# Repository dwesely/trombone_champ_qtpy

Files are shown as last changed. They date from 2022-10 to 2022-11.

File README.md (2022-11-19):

Moved into https://github.com/dwesely/trombone_champ, this branch is archived.

# Controller for trombone champ game

Control Trombone Champ by emulating a mouse with a QT-PY 2040 and VL53L0X distance sensor. This project was inspired by the [Adafruit Trombone Champ controller](https://learn.adafruit.com/circuitpython-trombone-champ-controller) by Liz Clark.

 This is a pared-down version of one I made [based on the Trinket m0](https://github.com/dwesely/trombone_champ_trinket).

## Operation

### Select precision
The 3-way switch specifies the precision when the device is plugged in. If the switch is in the middle position, the timing budget is set to 30ms. If the switch is set to one of the other positions, the timing budget will be set according to the table below. Blinks indicate which position was read.

The setting is only read once. To adjust the setting, unplug the device and plug it back in.

| Switch position | Timing Budget | Visual Indicator |
| --- | --- | --- |
| Left  | 20ms  | 2 blinks |
| Middle  | 30ms  | 3 blinks |
| Right  | 40ms  | 4 blinks |

### Select mode

3-way switch allows orientation to be inverted, or to disable the mouse emulation (so it doesn't interfere with operation outside the game).

When the switch is in the middle, no movement reports will be sent, and the scroll wheel (rotary encoder) will be operational.

When the switch is on one side, the distance measured by the device will be translated to the mouse position on the screen (farther distance = higher mouse).
When the switch is on the opposite side, the distance will be inverted (farther distance = lower mouse).

### Toot

The momentary switch clicks the left mouse button, activating toot.

### Navigation

Between songs, set to the 3-way switch to the middle to deactivate the vertical mouse, and to activate the scroll wheel. A rotary encoder acts as mouse wheel and the right mouse button. Scrolling the rotary encoder will scroll through available songs.

Hit the "Enter" key on the keyboard to select a song.

### Scaling Factor

You can adjust the potentiometer to set a scaling factor, to make the maximum detected distance higher or lower. This is used to make operation more comfortable for people with different sizes of arms.

## Other features 

Hardware debounce using a schmitt trigger to clean up "toot" command signal without adding processing complexity.

On board RGB LED indicates which which timing budget is selected, so the measurement precision can be changed without recoding.

JST connectors for input devices. 

### Libraries used
* adafruit_vl53l0x
* adafruit_bus_device
* neopixel
* [mouse_abs](https://gist.github.com/bitboy85/cdcd0e7e04082db414b5f1d23ab09005)

### Parts list
* QT PY RP2040 (Digikey: 1528-4900-ND)
* Adafruit VL53L0X Time of Flight Distance Sensor (Digikey: 1528-1814-ND)
* SN74AHC14N Schmitt Trigger (Digikey: 296-4550-5-ND)
* ANT13SECQE 3-way switch SPDT, ON-OFF-ON (Digikey: 2449-ANT13SECQE-ND)
* Momentary switch
* Rotary encoder
* 10k ohm linear rotary potentiometer
* (x8) 10k ohm 1/4 W resistor 
* (x4) 100nF ceramic capacitor
* JST connector sets (x1 2-pin, x1 4-pin, x1 5-pin)
* Generic toy foam dart gun as a project case (dollartree.com: SKU 323010)

### Connections
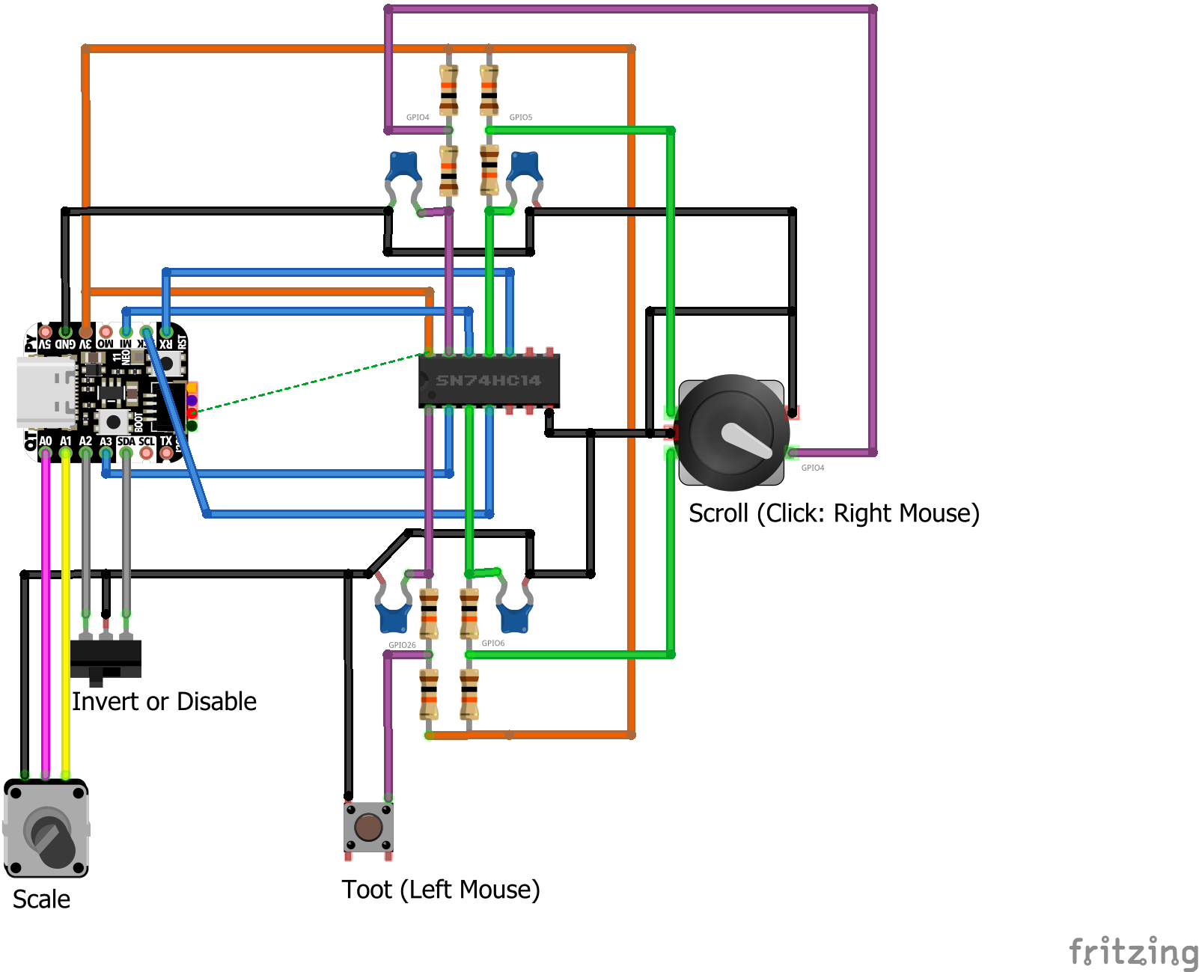
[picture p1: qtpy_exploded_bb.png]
Fritzing representation of parts and connections


## Lessons learned
* Rotary encoder pins must be sequential on the QT PY: https://github.com/adafruit/circuitpython/issues/5334
* The toy gun worked very well as a case, there was fairly little modification
* The mouse_abs library tended to scroll endlessly until I added "self.report[5] = 0" to the report functions.

The following image is a Fritzing representation of the collapsed circuit. Using 7-pin female headers, the QT PY was raised above the Schmitt Trigger, which was mounted using a 14-pin DIP socket. The ceramic capacitors are not shown in this representation, but they fit beneath the Schmitt Trigger, inside the DIP socket. This is probably a terrible way to do it, but it worked enough for me, and it looked cool in the foam dart gun case.

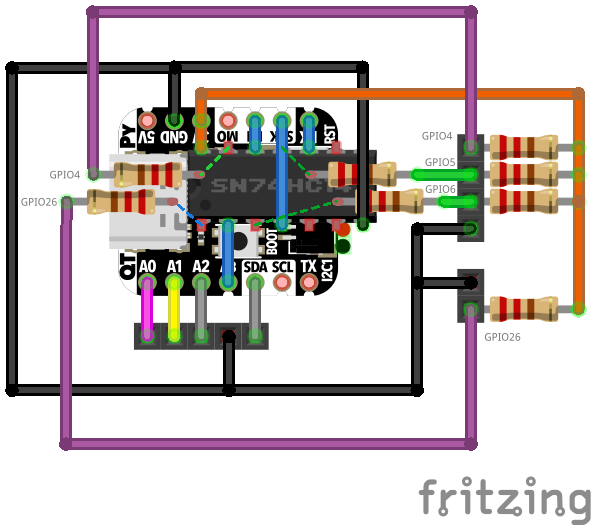
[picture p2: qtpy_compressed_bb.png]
Fritzing representation of compressed layout


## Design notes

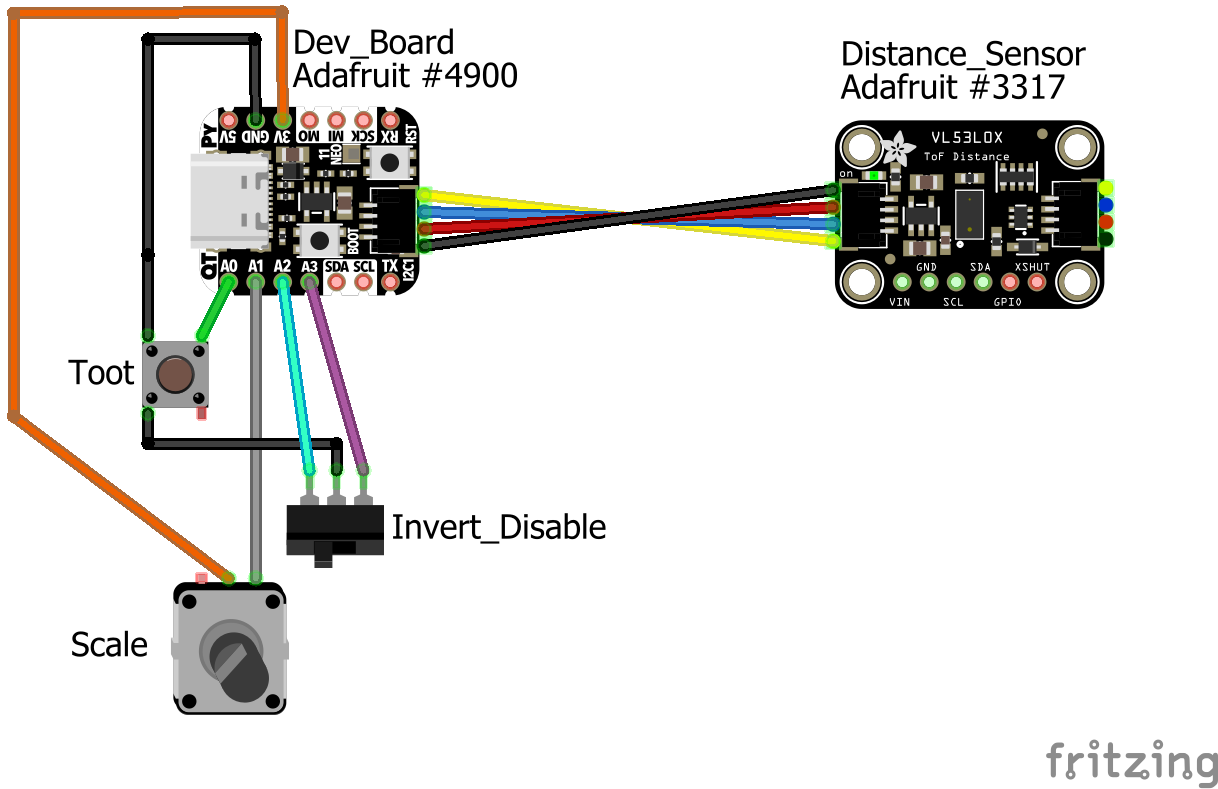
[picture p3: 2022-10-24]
qtpy_controller_bb.png

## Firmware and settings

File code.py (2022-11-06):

import time
import board
from mouse_abs import Mouse
import usb_hid
import busio
import adafruit_vl53l0x
import analogio
import digitalio
import neopixel
import rotaryio

def scale_distance_to_mouse(dist, scaling_coefficient=0.5, inverted=False):
    max_mouse = 32767
    min_dist = 50.0
    max_dist = 1000.0*scaling_coefficient
    percentage = (max_dist - dist)/(max_dist - min_dist)
    # print('Distance percentage: {0}'.format(percentage))
    if inverted:
        return (max_mouse - int(percentage * max_mouse))
    else:
        return int(percentage * max_mouse)

def scale_distance_to_color(dist, scaling_coefficient=0.5):
    max_color = 255
    min_dist = 50.0
    max_dist = 1000.0*scaling_coefficient
    if dist >= max_dist:
        return max_color
    elif dist <= min_dist:
        return 0
    else:
        percentage = (max_dist - dist)/(max_dist - min_dist)
        return int(percentage * max_color)

i2c = busio.I2C(board.SCL1, board.SDA1)
vl53 = adafruit_vl53l0x.VL53L0X(i2c)
vl53.measurement_timing_budget = 30000
vl53.start_continuous()

# set up toot trigger
toot = digitalio.DigitalInOut(board.A3)
toot.direction = digitalio.Direction.INPUT
toot.pull = digitalio.Pull.UP

# set up mouse active/invert switch
mouse = Mouse(usb_hid.devices)

mouse_active = digitalio.DigitalInOut(board.A2)
mouse_active.direction = digitalio.Direction.INPUT
mouse_active.pull = digitalio.Pull.UP

mouse_inverted = digitalio.DigitalInOut(board.SDA)
mouse_inverted.direction = digitalio.Direction.INPUT
mouse_inverted.pull = digitalio.Pull.UP

# set up neopixel (to indicate measurement precision)
# Use the active/invert switch to select timing budget on boot
pixel = neopixel.NeoPixel(board.NEOPIXEL, 1)

def blink(count):
    for i in range(0, count):
        pixel.fill((255, 0, 0))
        time.sleep(0.2)
        pixel.fill((0, 0, 0))
        time.sleep(0.2)
        
if mouse_active.value and mouse_inverted.value:
    vl53.measurement_timing_budget = 30000
    blink(3)
elif mouse_active.value:
    vl53.measurement_timing_budget = 20000
    blink(2)
else:
    vl53.measurement_timing_budget = 40000
    blink(4)

# done with neopixel
del pixel

# set up scale
scale_reference_voltage = digitalio.DigitalInOut(board.A1)
scale_reference_voltage.direction = digitalio.Direction.OUTPUT
scale_reference_voltage.value = True

scale = analogio.AnalogIn(board.A0)


tooting = False

smoothed_position = 0
# last_mouse_position = 0
# last_last_mouse_position = 0

# set up scroll wheel
encoder = rotaryio.IncrementalEncoder(board.RX, board.SCK)
last_wheel_position = 0
hat = digitalio.DigitalInOut(board.MISO)
hat.direction = digitalio.Direction.INPUT
hat.pull = digitalio.Pull.UP

# TODO: if hat is clicked, send "enter" keystroke instead of mouse button

# verbose = True

while True:
    # if verbose:
    #     time.sleep(1)

    if toot.value:
    #     if verbose:
    #         print('toot')
        if not tooting:
            mouse.press(Mouse.LEFT_BUTTON)
            tooting  = True
    elif tooting:
        mouse.release(Mouse.LEFT_BUTTON)
        tooting = False

    # if verbose:
    #     print(mouse_active.value, mouse_inverted.value)

    if mouse_active.value and mouse_inverted.value:
    #     if verbose:
    #         print('mouse disabled')

        # check mouse wheel only
        position = encoder.position
    #     if verbose:
    #         print('{0} -> {1}'.format(last_wheel_position, position))

        if position < last_wheel_position:
    #         if verbose:
    #             print('Move up')
            mouse.move(wheel=1)
        #     mouse.move(wheel=0)
        elif position > last_wheel_position:
            mouse.move(wheel=-1)
        #     mouse.move(wheel=0)
    #         if verbose:
    #             print('Move down')
    #     else:
    #         if verbose:
    #             print('hold still')
        mouse.release_all()
        last_wheel_position = position

        if hat.value == True:
        #     if verbose:
        #         print('click')
            # kbd.press(Keycode.ENTER)
            mouse.press(Mouse.RIGHT_BUTTON)
            while hat.value:
                # keep pressing until button released
                pass
            # kbd.release_all()
            mouse.release_all()
        continue
    # elif mouse_active.value:
    #     if verbose:
    #         print('mouse active')
    #     invert_mouse = False
    # elif mouse_inverted.value:
    #     if verbose:
    #         print('mouse inverted')
    #     invert_mouse = True

    # if verbose:
    #     print("\n")
    #     print("Range: {0}mm".format(vl53.range))
    #     print('Scale factor: {0}'.format(scale.value/65536))
    scale_factor = scale.value/65536
    mouse_position = scale_distance_to_mouse(vl53.range, scaling_coefficient=scale_factor, inverted=mouse_inverted.value)

    # Smooth the position so it doesn't wobble too much
    if -2000 > (smoothed_position - mouse_position) > 2000:
        # There was a big jump, skip smooothing this time
        smoothed_position = mouse_position
        # last_last_mouse_position = mouse_position
        # last_mouse_position = mouse_position
    else:
        # Simple Average
        smoothed_position = (smoothed_position + mouse_position)//2

        # kalman
        # first_term = mouse_position + 0.5*(last_mouse_position - mouse_position)
        # smoothed_position = int(first_term + 0.3333*(last_last_mouse_position - first_term))
    # if verbose:
    #     print(mouse_position, smoothed_position)
    mouse.move(x=14000, y=smoothed_position, wheel=0)
    # last_last_mouse_position = last_mouse_position
    # last_mouse_position = smoothed_position
    #break

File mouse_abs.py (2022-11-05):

# SPDX-FileCopyrightText: 2017 Dan Halbert for Adafruit Industries
#
# SPDX-License-Identifier: MIT

"""
`adafruit_hid.mouse.Mouse`
====================================================

* Author(s): Dan Halbert, Bitboy
https://gist.github.com/bitboy85/cdcd0e7e04082db414b5f1d23ab09005
"""
import time

# https://github.com/adafruit/circuitpython/issues/5461
def find_device(devices, *, usage_page, usage):
    """Search through the provided list of devices to find the one with the matching usage_page and
    usage."""
    if hasattr(devices, "send_report"):
        devices = [devices]
    for device in devices:
        if (
            device.usage_page == usage_page
            and device.usage == usage
            and hasattr(device, "send_report")
        ):
            return device
    raise ValueError("Could not find matching HID device.")
	
	
class Mouse:
    """Send USB HID mouse reports."""

    LEFT_BUTTON = 1
    """Left mouse button."""
    RIGHT_BUTTON = 2
    """Right mouse button."""
    MIDDLE_BUTTON = 4
    """Middle mouse button."""

    def __init__(self, devices):
        """Create a Mouse object that will send USB mouse HID reports.

        Devices can be a list of devices that includes a keyboard device or a keyboard device
        itself. A device is any object that implements ``send_report()``, ``usage_page`` and
        ``usage``.
        """
        self._mouse_device = find_device(devices, usage_page=0x1, usage=0x02)
        #print(dir(devices))
        # Reuse this bytearray to send mouse reports.
        # report[0] buttons pressed (LEFT, MIDDLE, RIGHT)
        # report[1] x1 movement
        # report[2] x2 movement
        # report[3] y1 movement
        # report[4] y2 movement
        # report[5] wheel movement
        self.report = bytearray(6)

        # Do a no-op to test if HID device is ready.
        # If not, wait a bit and try once more.
        try:
            self._send_no_move()
        except OSError:
            time.sleep(1)
            self._send_no_move()

    def press(self, buttons):
        """Press the given mouse buttons.

        :param buttons: a bitwise-or'd combination of ``LEFT_BUTTON``,
            ``MIDDLE_BUTTON``, and ``RIGHT_BUTTON``.

        Examples::

            # Press the left button.
            m.press(Mouse.LEFT_BUTTON)

            # Press the left and right buttons simultaneously.
            m.press(Mouse.LEFT_BUTTON | Mouse.RIGHT_BUTTON)
        """
        self.report[0] |= buttons
        self._send_no_move()

    def release(self, buttons):
        """Release the given mouse buttons.

        :param buttons: a bitwise-or'd combination of ``LEFT_BUTTON``,
            ``MIDDLE_BUTTON``, and ``RIGHT_BUTTON``.
        """
        self.report[0] &= ~buttons
        self._send_no_move()

    def release_all(self):
        """Release all the mouse buttons."""
        self.report[0] = 0
        self._send_no_move()

    def click(self, buttons):
        """Press and release the given mouse buttons.

        :param buttons: a bitwise-or'd combination of ``LEFT_BUTTON``,
            ``MIDDLE_BUTTON``, and ``RIGHT_BUTTON``.

        Examples::

            # Click the left button.
            m.click(Mouse.LEFT_BUTTON)

            # Double-click the left button.
            m.click(Mouse.LEFT_BUTTON)
            m.click(Mouse.LEFT_BUTTON)
        """
        self.press(buttons)
        self.release(buttons)

    def move(self, x=0, y=0, wheel=0):
        """Move the mouse and turn the wheel as directed.

        :param x: Set pointer on x axis. 32767 = 100% to the right
        :param y: Set pointer on y axis. 32767 = 100% to the bottom
        :param wheel: Rotate the wheel this amount. Negative is toward the user, positive
            is away from the user. The scrolling effect depends on the host.

        Examples::

            # Move 100 to the left. Do not move up and down. Do not roll the scroll wheel.
            m.move(1000, 3000, 0)
            # Same, with keyword arguments.
            m.move(x=1000, y=3000, wheel=0)


            # Roll the mouse wheel away from the user.
            m.move(wheel=1)
        """

        # Wheel
        while wheel != 0:
            partial_wheel = self._limit(wheel)
            print(wheel)
            self.report[5] = partial_wheel & 0xFF
            self._mouse_device.send_report(self.report)
            wheel -= partial_wheel

        # Coordinates
        x = self._limit_coord(x)
        y = self._limit_coord(y)
        # HID reports use little endian
        x1, x2 = (x & 0xFFFFFFFF).to_bytes(2, 'little')
        y1, y2 = (y & 0xFFFFFFFF).to_bytes(2, 'little')
        #print(x1)
        #print(x2)
        #print(y1)
        #print(y2)
        self.report[1] = x1
        self.report[2] = x2
        self.report[3] = y1
        self.report[4] = y2
        self.report[5] = 0
        self._mouse_device.send_report(self.report)

    def _send_no_move(self):
        """Send a button-only report."""
        self.report[1] = 0
        self.report[2] = 0
        self.report[3] = 0
        self.report[4] = 0
        self.report[5] = 0
        self._mouse_device.send_report(self.report)

    @staticmethod
    def _limit(dist):
        return min(127, max(-127, dist))

    @staticmethod
    def _limit_coord(coord):
        return min(32767, max(0, coord))

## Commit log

2022-10-24 Create code.py
    Placeholder code for now, just using an HC-SR04 until I pick up a better sensor
2022-11-05 Switch to QT PY 2040 and VL53L0X
2022-11-05 Adding Fritzing layouts
    [qtpy_compressed.fzz, qtpy_exploded.fzz]
